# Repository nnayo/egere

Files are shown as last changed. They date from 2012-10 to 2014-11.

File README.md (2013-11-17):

egere
=====

TRoll égère mini-rocket

Here are the code, the mechanical drawings and the electronic design of the mini-rocket named égère.

The code relies on other libraries:
 - nanoK
 - scalp

It is built using scons and avr-gcc suite.

The mechanical drawings are done with librecad and/or freecad.

Kicad is used for the electronics.

This projet is part of the activities of the amateur rocket TRoll association: http://clubtroll.no-ip.org (slow connection)

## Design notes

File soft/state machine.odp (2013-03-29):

## Égère state machine

cone_closed

cone_open

cone_open

time_out

cone_closed

time_out

time_out

time_out

take_off

time_out

time_out

time_out

cone_open

init

Cmde cone stop

Cmde aero stop

Led alive 0.25s

cone

opening

Cmde cone open

Time-out = 5s

aero

opening

Cmde aero open

Cmde cone stop

Time-out = 5s

Led alive 0.5s

Led open 0.5s

Cmde aero stop

parachute

Cmde cone stop

Cmde aero stop

Led open 1s

aero

open

braking

Cmde cone stop

Cmde aero open

Time-out = 0.1s

cone

closing

Time-out = 5s

cone

open

Cmde cone open

Cmde aero stop

Time-out = 0.1s

Led open 0.1s

Cmde cone close

Cmde aero close

Time-out = flight-time

Led alive 0.1s

cone

closed

Cmde cone close

Time-out = 1s

Led alive 0.1s

Led open off

flight

waiting

Cmde cone stop

Led alive 1s

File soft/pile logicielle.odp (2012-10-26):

## pile logicielle

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
driver I2C

driver RS232

HardWare

DPT/dispatcher : distribue les messages I2C et gère les priorités

BSC/basic services : fournit des services simples et bas niveau

RCF/reconfiguration : bascule d'un bus numérique à l'autre

DNA/dynamic node addressing : attribue les adresses des noeuds

CMN/commun : fournit les fonctions communes à tous les noeuds

SRV/surveillance : surveille les alimentations et les piles

MNT/minuterie : gère les phases de vol

XP/expérience : mesure l'éclairage de chaque LED

NAT/network address translation : pont I2C <-> RS232

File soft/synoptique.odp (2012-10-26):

## architecture logicielle

- système distribué (5 micro-contrôleurs)
- 2 bus numériques (nominal et redondant)
- alimentation par les bus
- 2 alimentations indépendantes pilotées
- abonnement automatique sur le bus
- dialogue inter-cartes
- 1 carte surveillance
- 1 carte expérience
- 3 cartes minuterie

## système distribué

- 5 micro-contrôleurs
  - surveillance
    - monitoring des alimentations
    - log des événements
    - gestion afficheur LCD
    - bus controler
  - expérience
    - mesure de l'éclairement de 16 LEDs
  - 3 minuteries
    - détection du décollage par vote majoritaire

## 2 bus numériques

- nominal et redondant
  - le nominal est prioritaire et actif par défaut
  - le redondant est là comme secours
- bus mixte
  - bus I²C
    - 3 fils (horloge, données et masse)
    - gestion hardware des collisions
  - puissance
    - 2 fils (+5V et masse)

## alimentation par les bus

- chaque bus fournit 1A sous 5V
- la présence du 5V sur le bus indique que les signaux I²C sont actifs
- si les 2 bus sont actifs, le nominal doit être utilisé.

## 2 alimentations indépendantes pilotées

- chaque alimentation posséde sa propre source d'énergie
- pour chacune, une source externe peut être connectée et prend le relais de la source interne
- la sortie de puissance n'est connectée qu'à un bus
- les signaux des 2 bus arrivent sur chaque carte afin de les activer ou les éteindre

## abonnement automatique

- 1 micro-contrôleur joue le rôle spécifique de Bus Controler (BC)
- les autres micro-contrôleurs (IS pour Intelligent Slave) doivent s'abonner auprès du BC en précisant leur adresse souhaitée et leur type
- les composants I²C normaux (BS pour Basic Slave) sont détectés par le BC

## abonnement automatique

- au fur et à mesure de la détection des BS, le BC met à jour une liste interne
- à chaque nouvel abonnement, le BC met à jour sa liste et la propage à tous les IS
- conséquence : les IS n'ont pas toujours la même adresse mais par leur type, ils peuvent retrouver un autre IS
- conséquence : on peut ajouter de nouveaux IS dans une architecture sans modifier les IS présents

## dialogue inter-cartes

- les messages échangés entre carte sont
  - courts pour limiter la prise de contrôle du bus
  - décrit par le format
    - destination
    - origine
    - commande/réponse
    - argument #1 (peut-être non significatif)
    - argument #2 (peut-être non significatif)
    - argument #3 (peut-être non significatif)
    - argument #4 (peut-être non significatif)

## carte surveillance

- monitoring des alimentations
  - mesure des tensions des piles
  - si le seuil inférieur de tension est franchi, bascule sur le bus redondant
  - si la tension fournie par le bus nominal chute, bascule sur le bus redondant
  - si connexion d'une source externe, bascule sur le bus correspondant (le nominal est toujours prioritaire)

## carte surveillance

- log des événements
  - à chaque démarrage de la carte, recherche du dernier log précédent et création d'une nouveau log à la suite (pas d'écrasement des logs les plus récents)
  - à chaque évément logiciel (abonnement d'IS, ...) ou matériel (chute de tension), une ligne est ajoutée dans le log

## carte surveillance

- Bus Controler
  - recherche des BS
  - enregistrement des IS
  - propagation des mises à jour de la liste des abonnés

## carte expérience

- IS
  - abonnement sur le bus pour permettre sa configuration
- mesure d'éclairement de 16 LEDs
  - le soleil sert de référence durant le vol
  - calcul de la rotation et de l'orientation de la fusée ”a posteriori”

## minuterie

- IS
  - abonnement sur le bus pour permettre sa configuration
  - vote avec les autres minuteries
  - émission des événements ”décollage”

## minuterie

- gestion des phases de vol
  - détection du décollage
    - 2 minuteries au moins doivent détecter le décollage dans la même plage de 100 ms
  - ouverture de la porte de la case parachute
    - temporisation programmable
    - angle d'ouverture programmable
    - commande déportée
  - fermeture de la porte de la case parachute
    - angle de fermeture programmable
    - commande déportée

## minuterie

- mode autonome
    - si la communication n'est possible sur aucun des bus (nominal ou redondant), bascule dans le mode autonome
      - la décision de décollage est prise unilatéralement

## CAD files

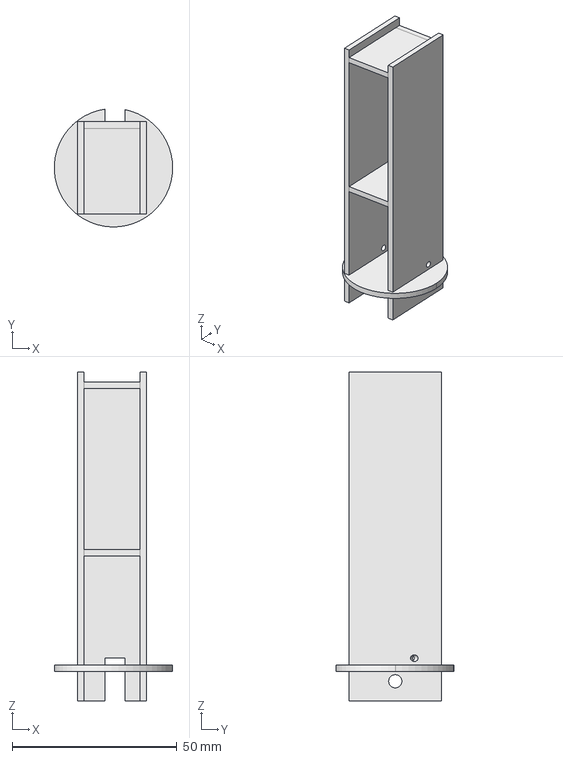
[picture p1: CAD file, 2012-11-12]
méca/égère.fcstd
36.0 x 35.8 x 100.0 mm

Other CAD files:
méca/separation v3.dxf

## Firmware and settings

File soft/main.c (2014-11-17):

#include "minut.h"
#include "servo.h"
#include "mpu6050.h"
#include "tk-off.h"

#include "drivers/timer2.h"
#include "utils/pt.h"
#include "utils/time.h"

#include "dispatcher.h"
#include "basic.h"
#include "reconf.h"
#include "dna.h"
#include "common.h"
#include "nat.h"
#include "log.h"
#include "time_sync.h"
#include "alive.h"
#include "cpu.h"

#include "avr/io.h"
#include "avr/interrupt.h"

#if 0
arduino	atmega	function
-------+-------+--------

D8      PB0     SS/
mosi    PB3     mosi
miso    PB4     miso
sck     PB5     sck

D9      PB1     servo cone
D10     PB2     servo aero

A4      PC4     sda
A5      PC5     scl

+9V     PWR     power in
GND     GND     ground


MPU-6050		function
---------------+--------

sda				sda
scl				scl

+5V				power in
GND				ground


servo cône		function
---------------+--------

+5V				power in
ctrl			control signal
GND				ground


servo aero		function
---------------+--------

+5V				power in
ctrl			control signal
GND				ground


switch			function
---------------+--------

GND				ground
sig				signal



relay card		function
---------------+--------

+9V				power in (accu)
GND				ground (accu)

+6V				power out (servo cone)
GND				ground (servo cone)
+6V				power out (servo aero)
GND				ground (servo aero)

+9V				power out (arduino)
+5V				power in (arduino)
GND				ground (arduino)

+5V				power out (MPU)
GND				ground (MPU)

sig				signal in (switch)
sig				signal out (arduino)
GND				ground (switch)

sda				sda (arduino)
sda				sda (MPU)
scl				scl(arduino)
scl				scl(MPU)

ctrl			ctrl servo aero (arduino)
ctrl			ctrl servo aero (servo)

ctrl			ctrl servo cone (arduino)
ctrl			ctrl servo cone (servo)

led alive		signal in (arduino)
led take-off	signal in (arduino)

#endif


// ------------------------------------------
// simavr options
//

#include "avr_mcu_section.h"

AVR_MCU(16000000, "atmega328p");

const struct avr_mmcu_vcd_trace_t simavr_conf[]  _MMCU_ = {
	{ AVR_MCU_VCD_SYMBOL("servo_cone"), .mask = _BV(PORTB1), .what = (void*)&PORTB, },
	{ AVR_MCU_VCD_SYMBOL("servo_aero"), .mask = _BV(PORTB2), .what = (void*)&PORTB, },
	{ AVR_MCU_VCD_SYMBOL("led_alive"), .mask = _BV(PORTB5), .what = (void*)&PORTB, },
	{ AVR_MCU_VCD_SYMBOL("led_open"), .mask = _BV(PORTB4), .what = (void*)&PORTB, },
	{ AVR_MCU_VCD_SYMBOL("cone_open_switch"), .mask = _BV(PORTB3), .what = (void*)&PINB, },

	{ AVR_MCU_VCD_SYMBOL("TWDR"), .what = (void*)&TWDR, },

	{ AVR_MCU_VCD_SYMBOL("SPDR"), .what = (void*)&SPDR, },

	{ AVR_MCU_VCD_SYMBOL("TCCR1A"), .what = (void*)&TCCR1A, },
	{ AVR_MCU_VCD_SYMBOL("TCCR1B"), .what = (void*)&TCCR1B, },
	{ AVR_MCU_VCD_SYMBOL("TCCR1C"), .what = (void*)&TCCR1C, },
	{ AVR_MCU_VCD_SYMBOL("TCNT1H"), .what = (void*)&TCNT1H, },
	{ AVR_MCU_VCD_SYMBOL("TCNT1L"), .what = (void*)&TCNT1L, },
	{ AVR_MCU_VCD_SYMBOL("OCR1AH"), .what = (void*)&OCR1AH, },
	{ AVR_MCU_VCD_SYMBOL("OCR1AL"), .what = (void*)&OCR1AL, },
	{ AVR_MCU_VCD_SYMBOL("OCR1BH"), .what = (void*)&OCR1BH, },
	{ AVR_MCU_VCD_SYMBOL("OCR1BL"), .what = (void*)&OCR1BL, },
	{ AVR_MCU_VCD_SYMBOL("ICR1H"), .what = (void*)&ICR1H, },
	{ AVR_MCU_VCD_SYMBOL("ICR1L"), .what = (void*)&ICR1L, },

	{ AVR_MCU_VCD_SYMBOL("TIMSK1"), .what = (void*)&TIMSK1, },
	{ AVR_MCU_VCD_SYMBOL("TIFR1"), .what = (void*)&TIFR1, },

	{ AVR_MCU_VCD_SYMBOL("TCNT2"), .what = (void*)&TCNT2, },

	{ AVR_MCU_VCD_SYMBOL("UDR0"), .what = (void*)&UDR0, },
	{ AVR_MCU_VCD_SYMBOL("UDRIE0"), .mask = _BV(UDRIE0), .what = (void*)&UCSR0B, },
	{ AVR_MCU_VCD_SYMBOL("UCSR0A"), .what = (void*)&UCSR0A, },

	{ AVR_MCU_VCD_SYMBOL("PINB"), .what = (void*)&PINB, },
	{ AVR_MCU_VCD_SYMBOL("PORTB"), .what = (void*)&PORTB, },
	{ AVR_MCU_VCD_SYMBOL("DDRB"), .what = (void*)&DDRB, },
};


// ------------------------------------------
// private definitions
//

//#define TIMER2_TOP_VALUE	78	// @ 8 MHz ==> 10 ms
#define TIMER2_TOP_VALUE	156	// @ 16 MHz ==> 10 ms


// ------------------------------------------
// private variables
//


// ------------------------------
// private functions
//

static void time(void* misc)
{
	(void)misc;

	// time update
	TIME_incr();
}


static u32 time_adjust(void)
{
	u8 val;
	u32 incr;

	val = TMR2_get_value();
	incr = TIME_get_incr();

	return incr * val / TIMER2_TOP_VALUE;
}


// ------------------------------
// public variables
//


// ------------------------------
// public functions
//

int main(void)
{
#if 0
	// if bad reset conditions
	if ( MCUSR & ( _BV(WDRF) | _BV(BORF) | _BV(EXTRF) ) ) {
		// loop for ever
		while (1)
			;
	}
	else {
		MCUSR = _BV(WDRF) | _BV(BORF) | _BV(EXTRF);
	}
#endif

	// init on-board time
	TIME_init(time_adjust);
	TIME_set_incr(10 * TIME_1_MSEC);

	// program and start timer2 for interrupt on compare every 10 ms
	TMR2_init(TMR2_WITH_COMPARE_INT, TMR2_PRESCALER_1024, TMR2_WGM_CTC, TIMER2_TOP_VALUE, time, NULL);
	TMR2_start();

	// enable interrupts
	sei();

	// init every common module
	DPT_init();
	BSC_init();
	CMN_init();
	NAT_init();
//	LOG_init();
	CPU_init();

	MNT_init();
	SRV_init();
	MPU_init();
	TKF_init();

	while (1) {
		// run every common module
		DPT_run();
		BSC_run();
		CMN_run();
		NAT_run();
//		LOG_run();
		CPU_run();

		MNT_run();
		SRV_run();
		MPU_run();
		TKF_run();
	}

	// this point is never reached
	return 0;
}

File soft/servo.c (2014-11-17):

#include "servo.h"

#include "dispatcher.h"

#include "drivers/timer1.h"
#include "utils/pt.h"
#include "utils/fifo.h"
#include "utils/time.h"

#include "avr/io.h"


// ------------------------------------------
// private definitions
//

#define IN_FIFO_SIZE	3
#define OUT_FIFO_SIZE	3

#define SERVO_DDR	DDRB
#define SERVO_PORT	PORTB
#define SERVO_PIN	PINB
#define SERVO_CONE	_BV(PB1)
#define SERVO_AERO	_BV(PB2)


// ------------------------------------------
// private variables
//

struct {
	pt_t pt_out;	// pt for sending thread
	pt_t pt_in;		// pt for receiving thread

	dpt_interface_t interf;	// interface to the dispatcher

	struct {
		s8 open_pos;		// open position
		s8 close_pos;		// closed position
	} cone;

	struct {
		s8 open_pos;		// open position
		s8 close_pos;		// closed position
	} aero;

	// incoming frames fifo
	fifo_t in;
	frame_t in_buf[IN_FIFO_SIZE];

	// outgoing frames fifo
	fifo_t out;
	frame_t out_buf[OUT_FIFO_SIZE];

	frame_t out_fr;	// frame for the sending thread
	frame_t in_fr;	// frame for the cmde thread

} SRV;


// ------------------------------------------
// private functions
//

// activate the cone servo to drive it to the given position
static void SRV_cone_on(s8 position)
{
	// compute the compare value according to the required position and the prescaler
	// for position = -90 degrees, signal up time shall be 1 ms so compare = 2000
	// for position = 0 degrees, signal up time shall be 1.5 ms so compare = 3000
	// for position = +90 degrees, signal up time shall be 2 ms so compare = 4000
	// compare = (position / 90) * 1000 + 3000
	// the computation shall be modified to fit in s16
	// the result is sure to fit in u16
	TMR1_compare_set(TMR1_A, ((s16)position * 100 / 9) + 3000);
}


// deactivate the cone servo to save power
static void SRV_cone_off(void)
{
	// setting the compare value to 0, ensure output pin is driven lo
	TMR1_compare_set(TMR1_A, 0);
}


// activate the aero servo to drive it to the given position
static void SRV_aero_on(s8 position)
{
	// compute the compare value according to the required position and the prescaler
	// for position = -90 degrees, signal up time shall be 1 ms so compare = 2000
	// for position = 0 degrees, signal up time shall be 1.5 ms so compare = 3000
	// for position = +90 degrees, signal up time shall be 2 ms so compare = 4000
	// compare = (position / 90) * 1000 + 3000
	// the computation shall be modified to fit in s16
	// the result is sure to fit in u16
	TMR1_compare_set(TMR1_B, ((s16)position * 100 / 9) + 3000);
}


// deactivate the aero servo to save power
static void SRV_aero_off(void)
{
	// setting the compare value to 0, ensure output pin is driven lo
	TMR1_compare_set(TMR1_B, 0);
}


static void SRV_drive(u8 servo, u8 sense)
{
	switch (servo) {
	case FR_SERVO_CONE:
		switch (sense) {
		case FR_SERVO_OPEN:		// open
			SRV_cone_on(SRV.cone.open_pos);
			break;

		case FR_SERVO_CLOSE:	// close
			SRV_cone_on(SRV.cone.close_pos);
			break;

		case FR_SERVO_OFF:
			SRV_cone_off();
			break;

		default:
			break;
		}
		break;

	case FR_SERVO_AERO:
		switch (sense) {
		case FR_SERVO_OPEN:		// open
			SRV_aero_on(SRV.aero.open_pos);
			break;

		case FR_SERVO_CLOSE:	// close
			SRV_aero_on(SRV.aero.close_pos);
			break;

		case FR_SERVO_OFF:
			SRV_aero_off();
			break;

		default:
			break;
		}
		break;

	default:
		break;
	}
}


static void SRV_cone_save(frame_t* fr)
{
	switch ( fr->argv[2] ) {
	case FR_SERVO_OPEN:		// open position
		SRV.cone.open_pos = fr->argv[3];
		break;

	case FR_SERVO_CLOSE:	// closed position
		SRV.cone.close_pos = fr->argv[3];
		break;

	default:
		// shall never happen
		fr->error = 1;
		break;
	}
}


static void SRV_cone_read(frame_t* fr)
{
	switch ( fr->argv[2] ) {
	case FR_SERVO_OPEN:		// open position
		fr->argv[3] = SRV.cone.open_pos;
		break;

	case FR_SERVO_CLOSE:	// closed position
		fr->argv[3] = SRV.cone.close_pos;
		break;

	default:
		// shall never happen
		fr->error = 1;
	}
}


static void SRV_aero_save(frame_t* fr)
{
	switch ( fr->argv[2] ) {
	case FR_SERVO_OPEN:		// open position
		SRV.aero.open_pos = fr->argv[3];
		break;

	case FR_SERVO_CLOSE:	// closed position
		SRV.aero.close_pos = fr->argv[3];
		break;

	default:
		// shall never happen
		fr->error = 1;
		break;
	}
}


static void SRV_aero_read(frame_t* fr)
{
	switch ( fr->argv[2] ) {
	case FR_SERVO_OPEN:		// open position
		fr->argv[3] = SRV.aero.open_pos;
		break;

	case FR_SERVO_CLOSE:	// closed position
		fr->argv[3] = SRV.aero.close_pos;
		break;

	default:
		// shall never happen
		fr->error = 1;
	}
}


static void SRV_position(frame_t* fr)
{
	switch ( fr->argv[0] ) {
	case FR_SERVO_CONE:
		switch ( fr->argv[1] ) {
		case FR_SERVO_SAVE:	// save
			SRV_cone_save(fr);
			break;

		case FR_SERVO_READ:	// read
			SRV_cone_read(fr);
			break;

		default:
			// shall never happen
			fr->error = 1;
			break;
		}
		break;

	case FR_SERVO_AERO:
		switch ( fr->argv[1] ) {
		case FR_SERVO_SAVE:	// save
			SRV_aero_save(fr);
			break;

		case FR_SERVO_READ:	// read
			SRV_aero_read(fr);
			break;

		default:
			// shall never happen
			fr->error = 1;
			break;
		}
		break;

	default:
		// shall never happen
		fr->error = 1;
		break;
	}
}


static PT_THREAD( SRV_in(pt_t* pt) )
{
	u8 swap;

	PT_BEGIN(pt);

	// if no incoming frame is available
	PT_WAIT_UNTIL(pt, OK == FIFO_get(&SRV.in, &SRV.in_fr) );

	// if it is a response
	if (SRV.in_fr.resp) {
		// ignore it

		// release the dispatcher
		DPT_unlock(&SRV.interf);

		// and restart waiting
		PT_RESTART(pt);
	}

	SRV.in_fr.error = 0;

	switch (SRV.in_fr.cmde) {
		case FR_MINUT_SERVO_CMD:
			// drive the servo
			SRV_drive(SRV.in_fr.argv[0], SRV.in_fr.argv[1]);
			break;

		case FR_MINUT_SERVO_INFO:
			SRV_position(&SRV.in_fr);
			break;

		default:
			// shall never happen
			SRV.in_fr.error = 1;
			break;
	}

	// send the response
	swap = SRV.in_fr.orig;
	SRV.in_fr.orig = SRV.in_fr.dest;
	SRV.in_fr.dest = swap;
	SRV.in_fr.resp = 1;
	//SRV.in_fr.nat = 0;
	PT_WAIT_UNTIL(pt, OK == FIFO_put(&SRV.out, &SRV.in_fr));

	// and restart waiting for incoming command
	PT_RESTART(pt);

	PT_END(pt);
}


static PT_THREAD( SRV_out(pt_t* pt) )
{
	PT_BEGIN(pt);

	// wait until a frame to send is available
	PT_WAIT_UNTIL(pt, OK == FIFO_get(&SRV.out, &SRV.out_fr));

	// send it throught the dispatcher
	DPT_lock(&SRV.interf);

	// some retry may be necessary
	PT_WAIT_UNTIL(pt, OK == DPT_tx(&SRV.interf, &SRV.out_fr));

	// release the dispatcher
	DPT_unlock(&SRV.interf);

	// loop back at start
	PT_RESTART(pt);

	PT_END(pt);
}


// ------------------------------------------
// public functions
//
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

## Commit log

2012-10-25 first release of relay board
    [égère.brd, égère.sch]
2012-10-25 first release of mechanic drawings
    [separation v3.dxf, égère.fcstd]
2012-10-27 open switch must not be left floating and thus shall be forced to GND or to +5V
    [égère.brd, égère.sch]
2012-11-12 update to timer1 API and capabilities
2012-11-12 add take-off detection thread
2012-11-12 generation of the EEPROM frames
2012-11-12 add MPU thread for data acquisitions
2012-11-12 no longer track those files
2012-11-12 update design
    [égère.fcstd]
2013-03-08 eeprom frames are now generated into a .c file and embedded into .eeprom section
2013-03-08 several more registers are spied NAT is used for frame real-time spying
2013-03-08 update to fit frame.py update
2013-03-08 prevent applications to start before scalp has finished its init
    [minut.c, minut.py, mpu6050.c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]
2013-03-24 servo renaming and clean-up
2013-03-29 correct mnemo names and values
    [minut.py]
2013-03-29 new thread prirorities correct unlocking change acquisition rate
    [mpu6050.c, servo.c]
2013-03-29 prevent sending multiple take-off frame
2013-03-29 open led is nw blinking when cone is opened at start-up
2013-03-31 more gtkwave traces
2013-03-31 PWM generation shall use ICR1 for 20ms period
2013-11-16 link points to scalp directory as frame.py is better there
2013-11-17 intialize git filters
2014-01-09 add blocking thread for cone
2014-01-09 correct automata and servo driving
    [minut.c, servo.c]
2014-08-31 correct path for frame.py
2014-08-31 better git filtering
2014-11-17 add the simulator to test
    [sim_egere.cfg]
